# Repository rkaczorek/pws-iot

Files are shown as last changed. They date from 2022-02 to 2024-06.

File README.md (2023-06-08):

# pws-iot
Personal Weather Station IoT. It reads various environmental sensors and publishes values to MQTT server via wireless connection.

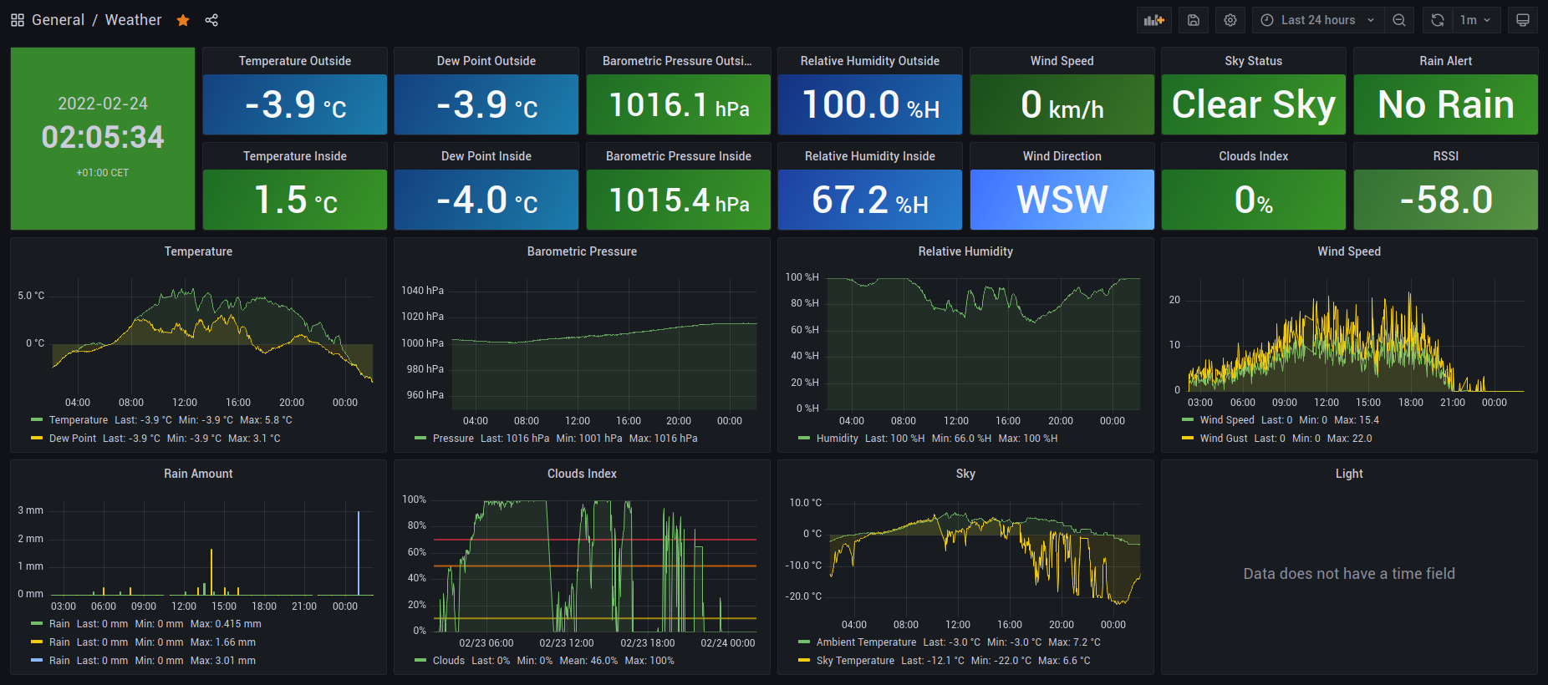
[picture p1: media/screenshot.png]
alt img1


# Features
- Weather Sensors
    - Temperature
    - Humidity
    - Pressure
    - Dew Point
    - Wind Speed
    - Wind Gust
    - Wind Direction
    - Rain Gauge
    - Clouds
    - Light
- WiFi connection
- MQTT messaging
- Manual or Auto polling
- Home Assistant integration

# Requirements
- MQTT server
- Node-Red (optional - only for routing data to InfluxDB)
- InfluxDB (optional - only for data persistency)

# Supported MCUs
- Arduino Nano 33 IoT
- Arduino MKR WiFi 1000
- Arduino MKR WiFi 1010
- Arduino Uno Wifi Rev2
- ESP8266

# Supported GPIO connected (A0, D10, D11) sensors
- Weather Meters (wind direction, wind speed, rainfall) (https://www.sparkfun.com/products/8942)

# Supported I2C sensors
- BME280 (temperature, humidity, pressure)
- MLX90614 (ambient temperature, object temperature)
- VEML7700 (light)

# Home Assistant
You can easily integrate Personal Weather Station IoT with your Home Assistant.
Just make sure that MQTT Integration is installed on Home Assistant. We are using Home Assistant 
autodiscovery feature to add Personal Weather Station device and sensor entities automatically.

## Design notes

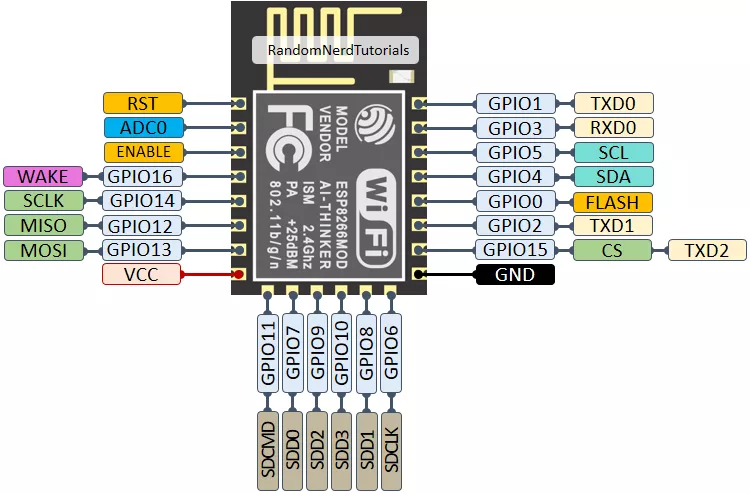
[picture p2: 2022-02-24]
hardware/Pinouts/Pinout-ESP8266-ESP-12E.png

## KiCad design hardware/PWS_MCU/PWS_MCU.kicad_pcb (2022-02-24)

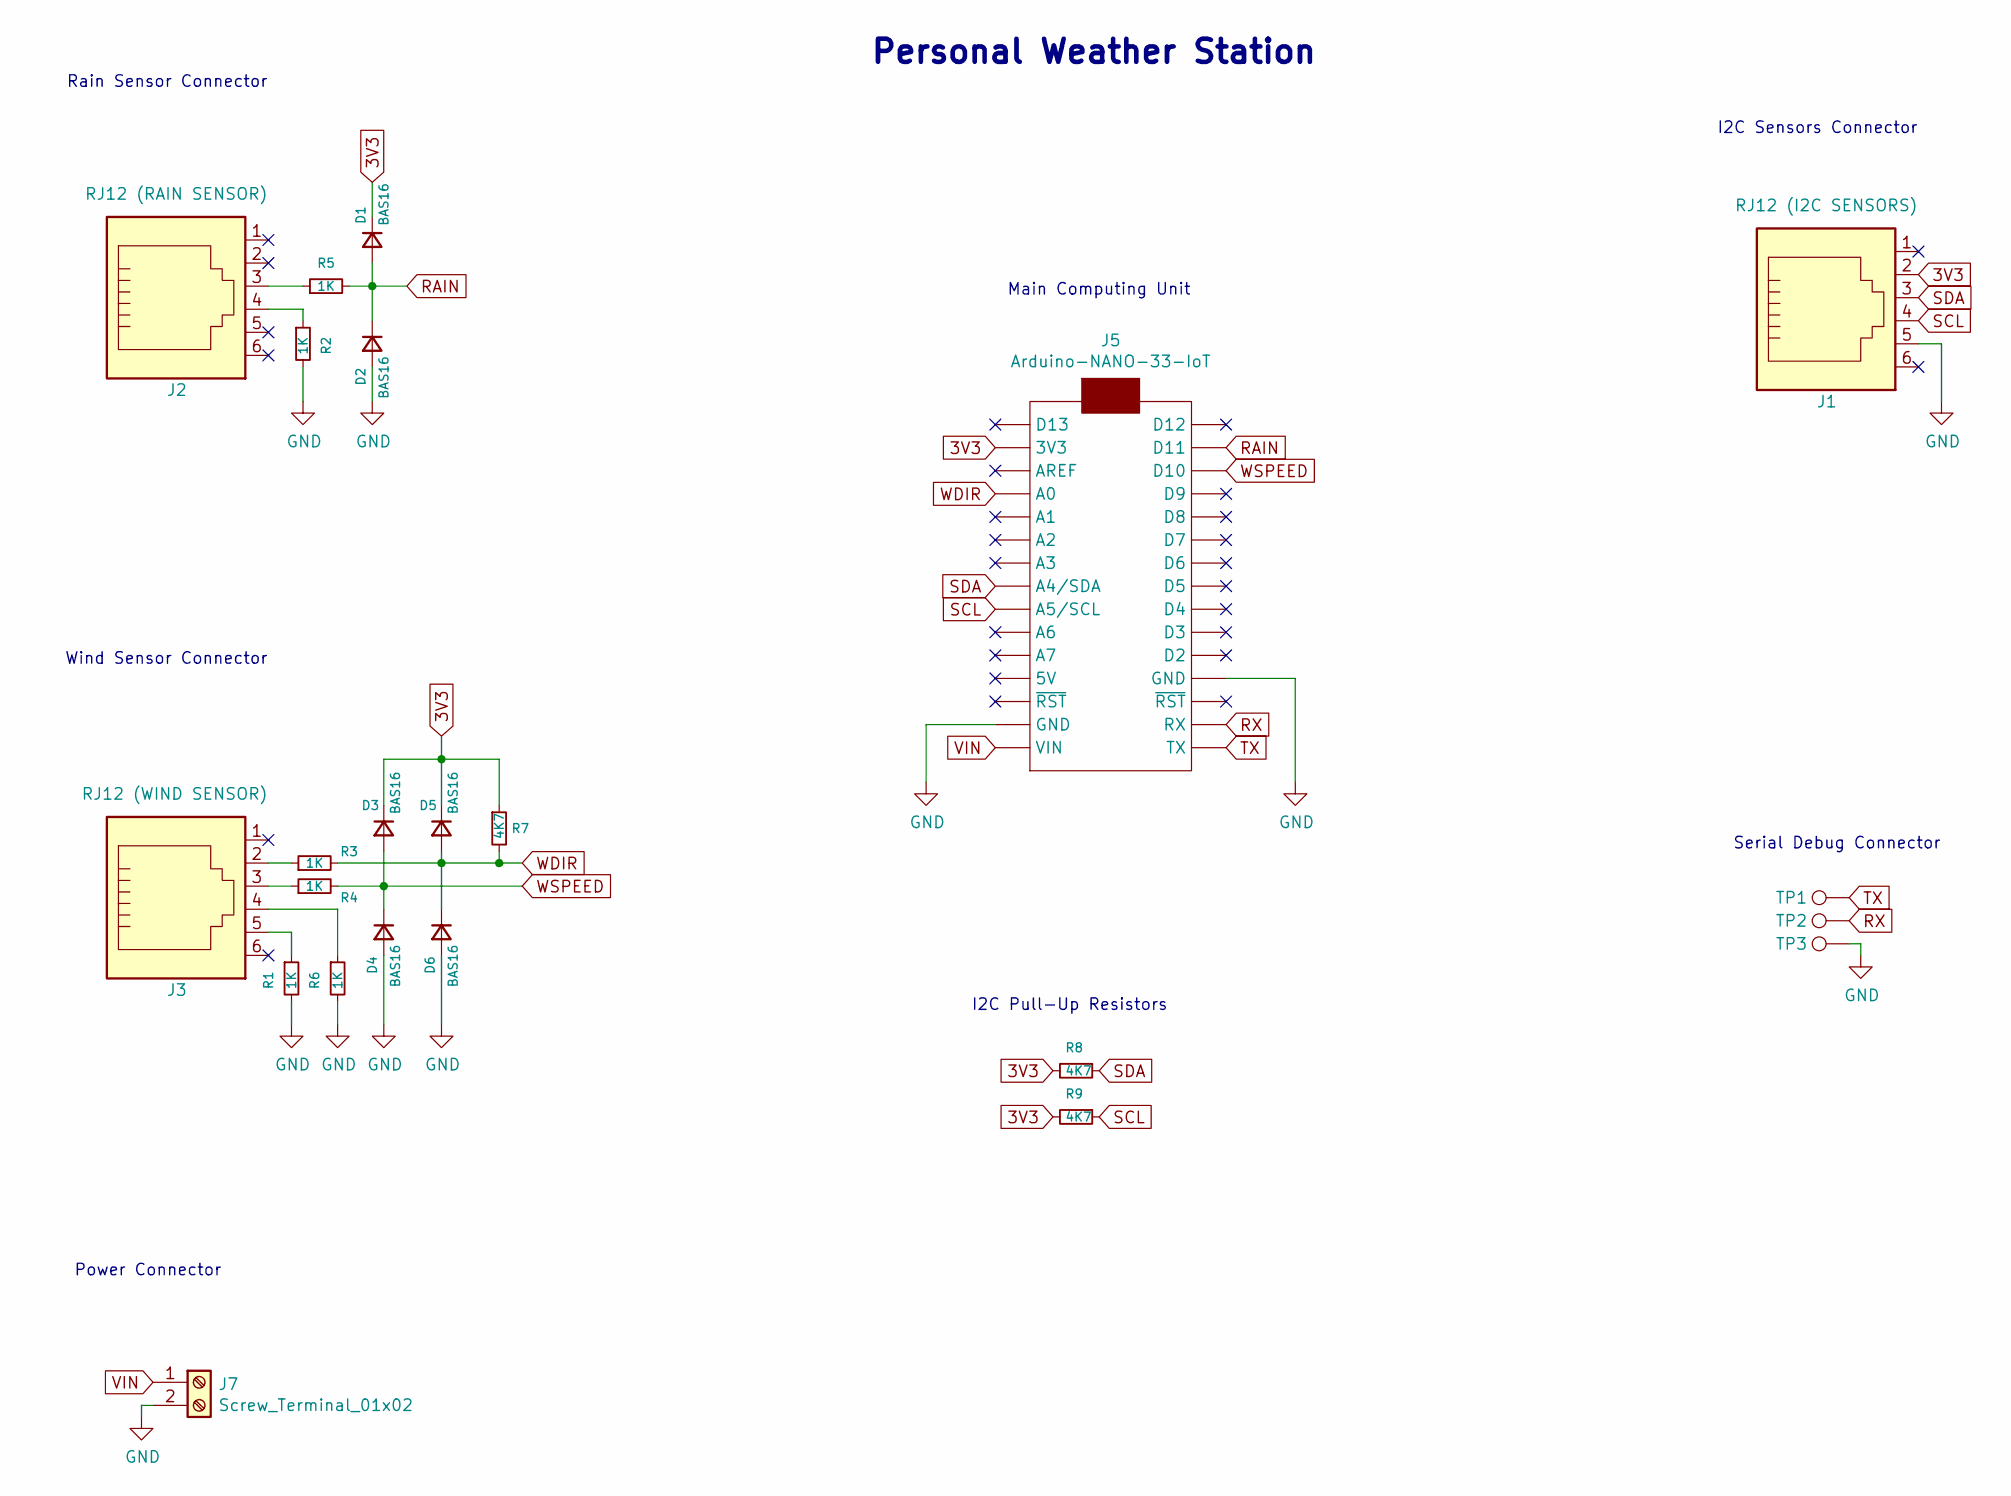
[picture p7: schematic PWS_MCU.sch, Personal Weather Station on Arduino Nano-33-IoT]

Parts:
D1, D2, D3, D4, D5, D6: BAS16; D_SOD-123
J1: RJ12 (I2C SENSORS); molex_6p6c
J2: RJ12 (RAIN SENSOR); molex_6p6c
J3: RJ12 (WIND SENSOR); molex_6p6c
J5: Arduino-NANO-33-IoT; NANO_33_Footprint_SMD_Castell
J7: Screw_Terminal_01x02; TerminalBlock_Phoenix_MPT-2.54mm_2pol
R1, R2, R3, R4, R5, R6: 1K; R_0603_HandSoldering
R7, R8, R9: 4K7; R_0603_HandSoldering
TP1, TP2, TP3: TestPoint; Measurement_Point_Square-SMD-Pad_Small

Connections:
3V3: D1.1 (K), D3.1 (K), D5.1 (K), J1.2, J5.2 (3V3), R7.1, R8.2, R9.2
GND: D2.2 (A), D4.2 (A), D6.2 (A), J1.5, J5.14 (GND), J5.19 (GND), J7.2, R1.2, R2.2, R6.2, TP3.1
unnamed: J2.3, R5.1
unnamed: J2.4, R2.1
unnamed: J3.2, R3.1
unnamed: J3.3, R4.1
unnamed: J3.4, R6.1
unnamed: J3.5, R1.1
RAIN: D1.2 (A), D2.1 (K), J5.29 (D11), R5.2
RX: J5.17 (RX), TP2.1
SCL: J1.4, J5.9 (A5/SCL), R9.1
SDA: J1.3, J5.8 (A4/SDA), R8.1
TX: J5.16 (TX), TP1.1
VIN: J5.15 (VIN), J7.1
WDIR: D5.2 (A), D6.1 (K), J5.4 (A0), R3.2, R7.2
WSPEED: D3.2 (A), D4.1 (K), J5.28 (D10), R4.2

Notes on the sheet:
Main Computing Unit
Rain Sensor Connector
Wind Sensor Connector
I2C Pull-Up Resistors
I2C Sensors Connector
Serial Debug Connector
Personal Weather Station
Power Connector

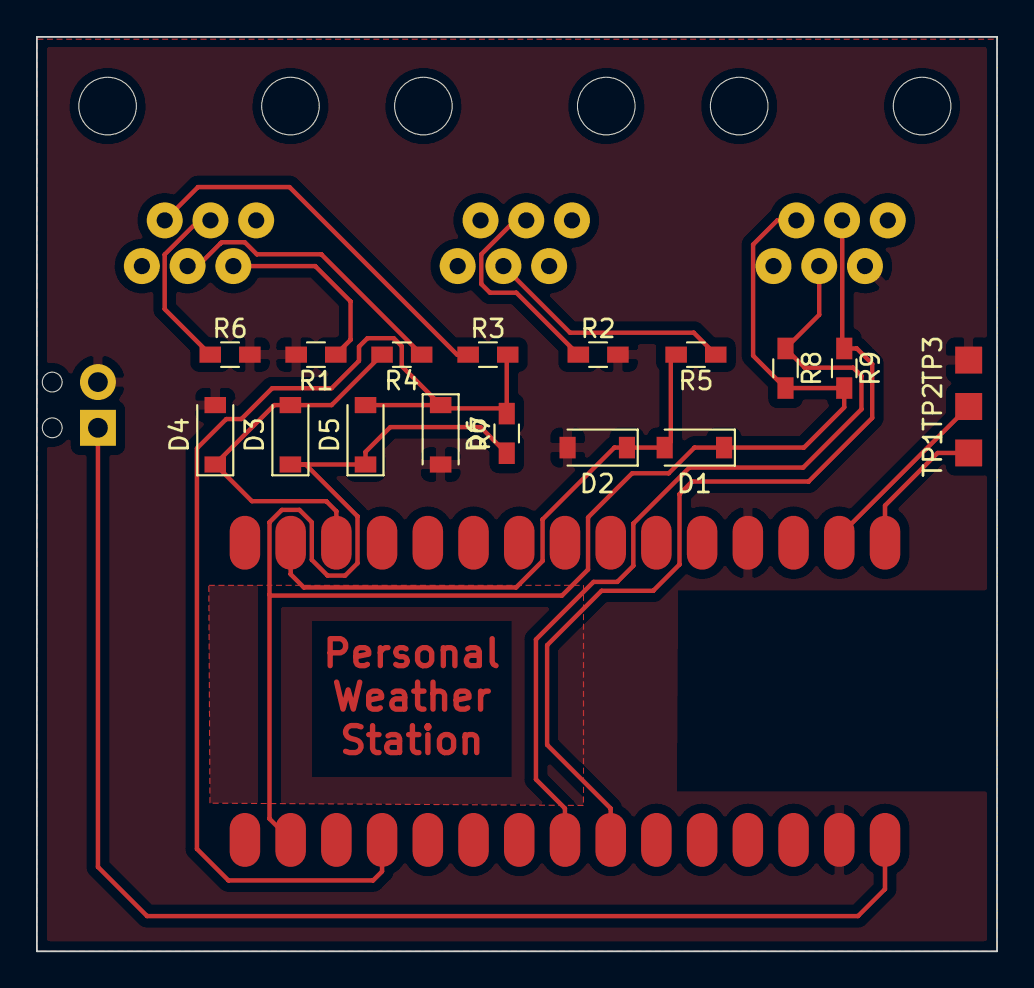
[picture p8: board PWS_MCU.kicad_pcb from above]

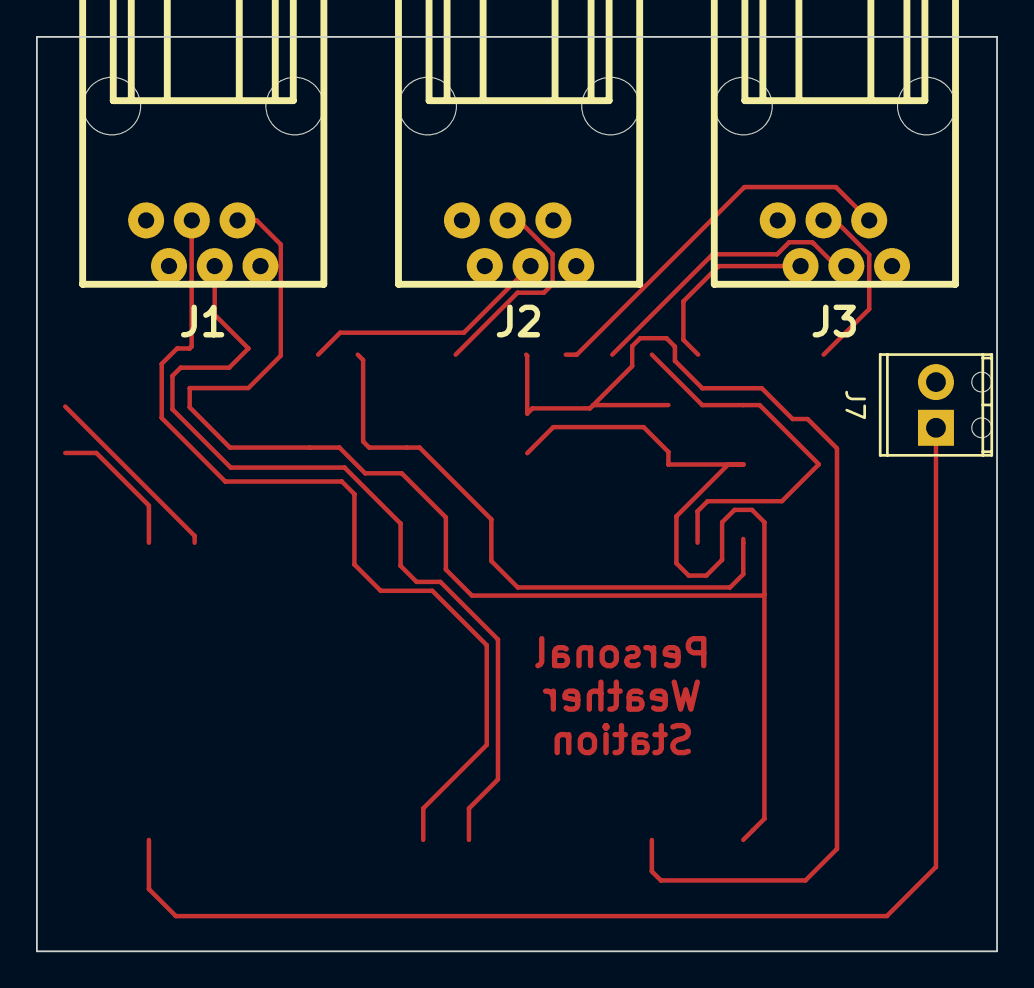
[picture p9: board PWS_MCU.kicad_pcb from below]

Board: 2 copper layers, 53.3 x 50.8 mm, 23 parts (4 on the bottom side), 16 nets.

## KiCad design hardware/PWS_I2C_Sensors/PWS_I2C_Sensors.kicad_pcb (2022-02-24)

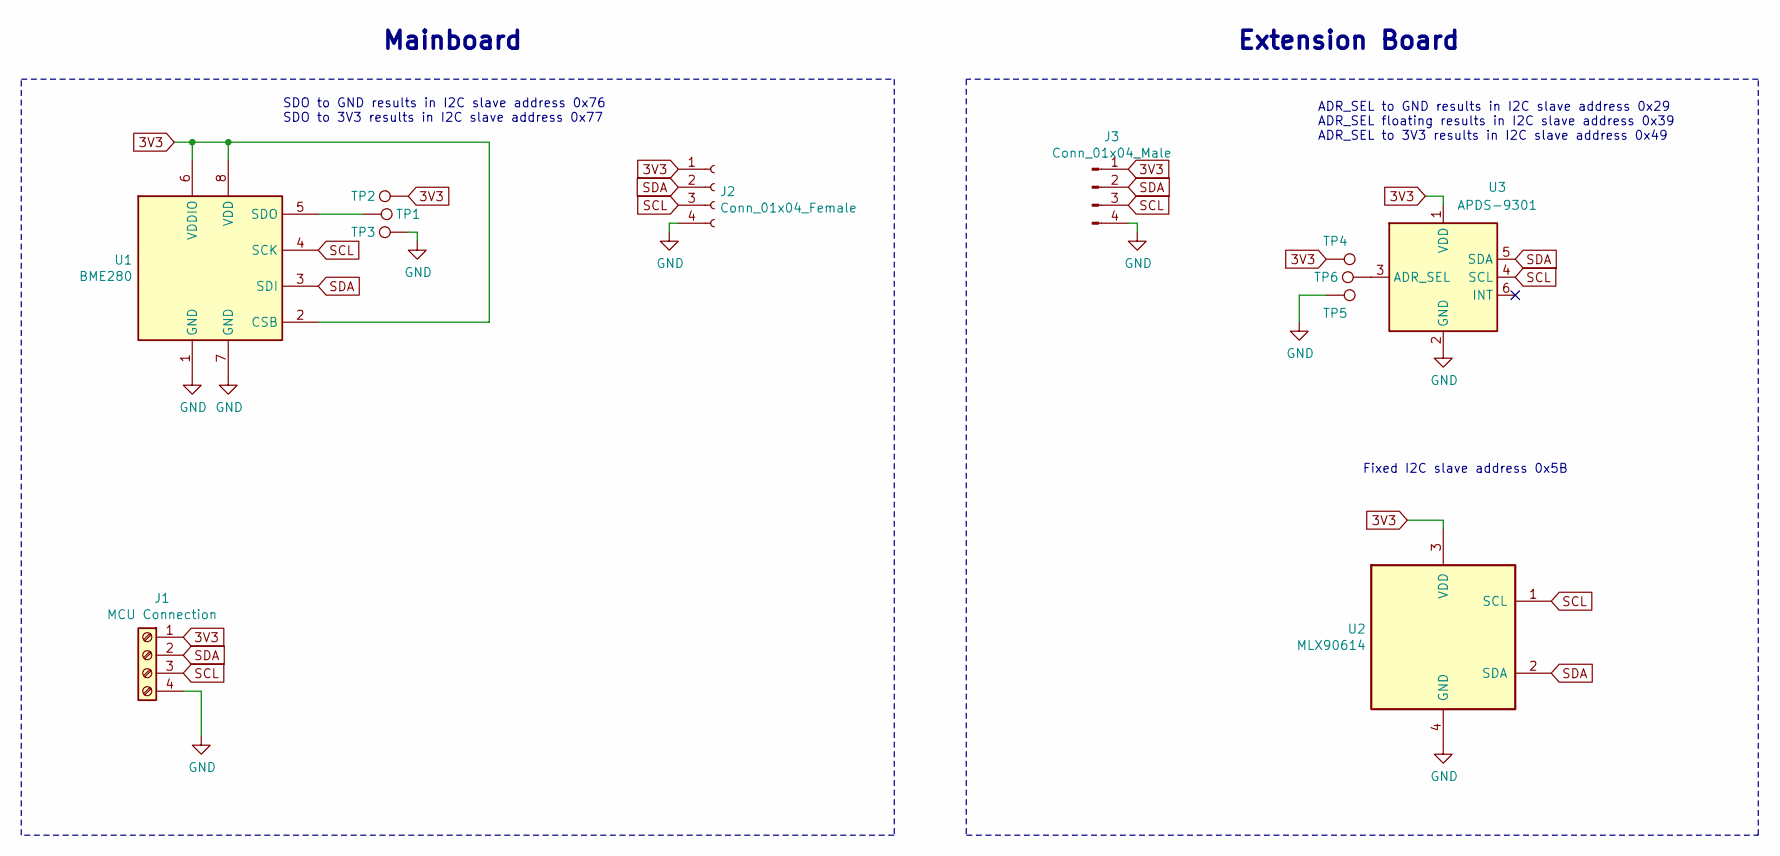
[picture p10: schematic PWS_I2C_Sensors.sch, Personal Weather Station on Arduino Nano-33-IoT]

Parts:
J1: MCU Connection; TerminalBlock_Phoenix_MPT-2.54mm_4pol
J2: Conn_01x04_Female; Pin_Header_Angled_1x04_Pitch2.54mm
J3: Conn_01x04_Male; Pin_Header_Straight_1x04_Pitch2.54mm
TP1, TP2, TP3, TP4, TP5, TP6: TestPoint; Measurement_Point_Square-SMD-Pad_Small
U1: BME280; Bosch_LGA-8_2.5x2.5mm_Pitch0.65mm_ClockwisePinNumbering
U2: MLX90614
U3: APDS-9301; Broadcom_APDS-9301

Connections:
3V3: J1.1, J2.1, J3.1, TP2.1, TP4.1, U1.2 (CSB), U1.6 (VDDIO), U1.8 (VDD), U2.3 (VDD), U3.1 (VDD)
GND: J1.4, J2.4, J3.4, TP3.1, TP5.1, U1.1 (GND), U1.7 (GND), U2.4 (GND), U3.2 (GND)
unnamed: TP1.1, U1.5 (SDO)
unnamed: TP6.1, U3.3 (ADR_SEL)
SCL: J1.3, J2.3, J3.3, U1.4 (SCK), U2.1 (SCL), U3.4 (SCL)
SDA: J1.2, J2.2, J3.2, U1.3 (SDI), U2.2 (SDA), U3.5 (SDA)

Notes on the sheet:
Mainboard
Extension Board
SDO to GND results in I2C slave address 0x76 SDO to 3V3 results in I2C slave address 0x77
ADR_SEL to GND results in I2C slave address 0x29 ADR_SEL floating results in I2C slave address 0x39 ADR_SEL to 3V3 results in I2C slave address 0x49
Fixed I2C slave address 0x5B

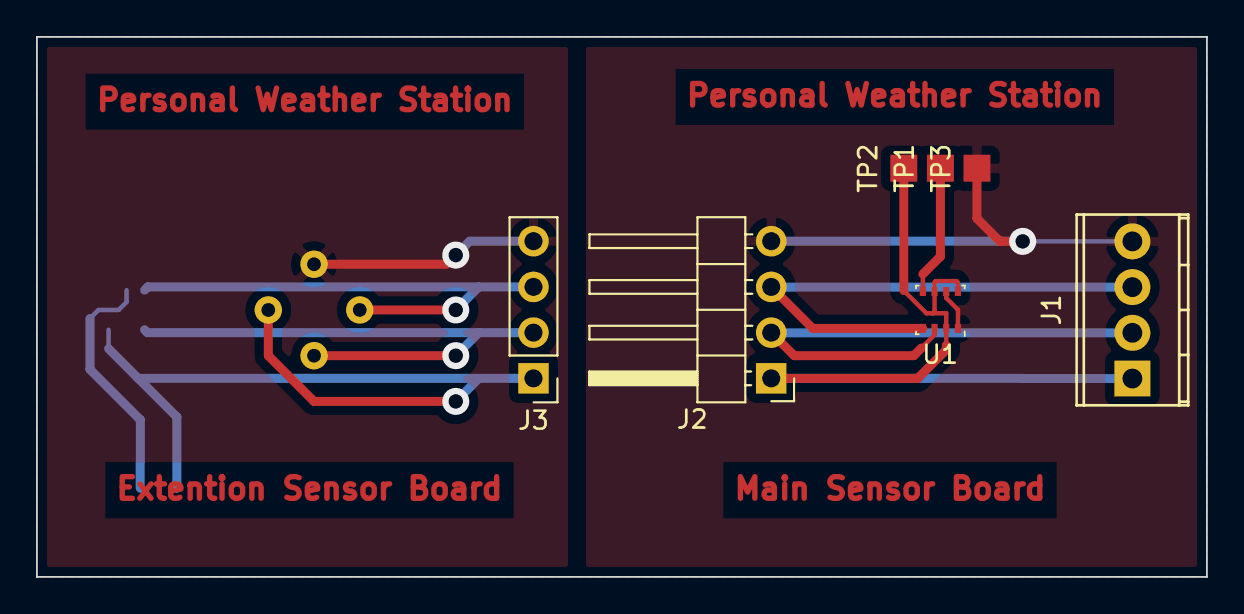
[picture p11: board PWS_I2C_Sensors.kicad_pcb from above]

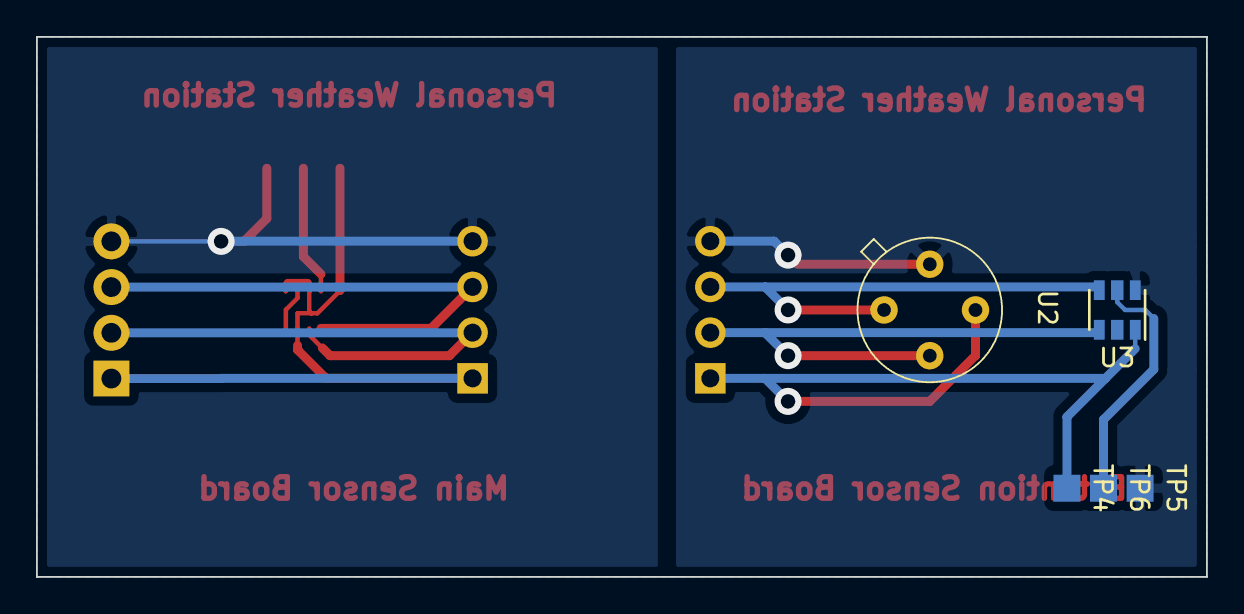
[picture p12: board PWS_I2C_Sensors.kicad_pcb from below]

Board: 2 copper layers, 65.0 x 30.0 mm, 12 parts (5 on the bottom side), 6 nets.

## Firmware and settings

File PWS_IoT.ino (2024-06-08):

/*
  Name: Personal Weather Station IoT
  By: Radek Kaczorek, (C) 2021 - 2024
  License: GNU General Public License v3.0

  This code reads various environmental sensors and publishes values to MQTT server via wireless connection.

  Supported MCUs:
  - Arduino Nano 33 IoT
  - Arduino MKR WiFi 1000
  - Arduino MKR WiFi 1010
  - Arduino Uno Wifi Rev2
  - ESP8266

  Supported GPIO connected (A0, D10, D11) sensors:
  - Weather Meters (wind direction, wind speed, rainfall) (https://www.sparkfun.com/products/8942)

  Supported I2C sensors:
  - BME280 (temperature, humidity, pressure)
  - MLX90614 (ambient temperature, object temperature)
  - VEML7700 (light)

  Set these variables in PWS_IoT.h:
    WIFI_SSID "wifi_name"
    WIFI_PASS "wifi_password"
    MQTT_HOST "mqtt_address"
    MQTT_PORT 1883
    MQTT_USER "mqtt_user"
    MQTT_PASS "mqtt_password"
    MQTT_ROOT_TOPIC "environment"
    MQTT_DEVICE_ID "pws"
    MQTT_DEVICE_ID_TO_HOSTNAME true
    DEBUG false
    WIND_DIR_CORRECTION 60
    WIND_AVERAGING_TIME 10000
    CLOUDS_AVERAGING_TIME 5000
    HOMEASSISTANT
    HA_DISCOVERY_TOPIC
*/

#define VERSION 1.4

#include "PWS_IoT.h"

#if defined(ARDUINO_SAMD_MKRWIFI1010) || defined(ARDUINO_SAMD_NANO_33_IOT) || defined(ARDUINO_AVR_UNO_WIFI_REV2)
  #include <WiFiNINA.h> // https://www.arduino.cc/en/Reference/WiFiNINA // https://github.com/arduino-libraries/WiFiNINA
#elif defined(ARDUINO_SAMD_MKR1000)
  #include <WiFi101.h> // https://www.arduino.cc/en/Reference/WiFi101
#elif defined(ARDUINO_ESP8266_ESP12)
  #include <ESP8266WiFi.h> // https://github.com/esp8266/Arduino/tree/master/libraries/ESP8266WiFi
#endif

#include <Wire.h> // https://github.com/esp8266/Arduino/tree/master/libraries/Wire
#include <ArduinoMqttClient.h> // https://github.com/arduino-libraries/ArduinoMqttClient
#include <ArduinoOTA.h> // https://github.com/jandrassy/ArduinoOTA
#include <ArduinoJson.h>  // https://github.com/bblanchon/ArduinoJson
#include <Adafruit_BME280.h> // https://github.com/adafruit/Adafruit_BME280_Library
#include <Adafruit_MLX90614.h> // https://github.com/adafruit/Adafruit-MLX90614-Library
#include <Adafruit_VEML7700.h> // https://github.com/adafruit/Adafruit_VEML7700
#include <Cardinal.h> // https://github.com/DaAwesomeP/arduino-cardinal
#include <SimpleTime.h>

#include <vector>
#include <numeric>

#define SEALEVELPRESSURE_HPA  (1013.25) // used for altitude calculation based on pressure
#define sgn(x) ((x) < 0 ? -1 : ((x) > 0 ? 1 : 0)) // used for arithmetic sign of a value (needed by cloud detection algorithm)

// Debug
bool DEBUG = false;

// ===================================================================
//                       Enable/Disable sensors
// ===================================================================
// -------------------------- autodetected ---------------------------
int bme_sensor = 0; // Temperature, Humidity, Pressure
int mlx_sensor = 0; // Sky temperature / Clouds
int wind_sensor = 0; // Wind Speed - set to 1 to enable
int veml_sensor = 0; // Light
// -------------------------- set manually ---------------------------
int rainfall_sensor = 1; // Rainfall - set to 1 to enable
// ===================================================================

// hardware pins definitions
const byte WDIR = A0;
const byte WSPEED = 10;
const byte RAINFALL = 11;

// volatiles are subject to modification by IRQs
volatile long lastWindIRQ = 0;
volatile long windClicks = 0;
volatile long lastRainIRQ = 0;
volatile long rainClicks = 0;

// last checks
unsigned long lastWindMillis = 0;
unsigned long lastCloudsMillis = 0;
unsigned long lastCheck = 0;

// statistical vars
std::vector<float> windSpeed;
std::vector<int> windDir;
float windGustSpeed = 0;
std::vector<int> windGustDir;
std::vector<float> irAmbient;
std::vector<float> irSky;

// polling vars
unsigned long timestamp = 0; // set tickmark for auto polling
unsigned int polling = 60; // auto polling time

// mqtt
const char* mqtt_host = MQTT_HOST;
int mqtt_port = MQTT_PORT;
const char* mqtt_user = MQTT_USER;
const char* mqtt_pass = MQTT_PASS;

// mqtt topics
char mqtt_root_topic[32] = MQTT_ROOT_TOPIC; // eg. environment
char mqtt_device_id[32] = MQTT_DEVICE_ID; // eg. mysensor
char mqtt_device_topic[64]; // = mqtt_root_topic/mqtt_device_id
char mqtt_setroot_topic[36]; // eg. environment/set
char mqtt_setname_topic[70]; // eg. environment/mysensor/set
char mqtt_status_topic[76]; // eg. environment/mysensor/status
char mqtt_poll_topic[71]; // eg. environment/mysensor/poll
char mqtt_control_topic[74]; // eg. environment/mysensor/control

byte mac[6]; // 6 byte array to hold the MAC address
char hostname[32]; // an array to hold wifi hostname

WiFiClient wifiClient;
MqttClient mqttClient(wifiClient);
int wifiStatus = WL_IDLE_STATUS;
WiFiServer server(23);

Adafruit_BME280 bme; // BME280 sensor - temperature, humidity, pressure
Adafruit_MLX90614 mlx = Adafruit_MLX90614(); // MLX90614 sensor - infrared termometer
Adafruit_VEML7700 veml = Adafruit_VEML7700(); // VEML7700 sensor - ambient light

Cardinal cardinal; // Cardinal direction NESW

void rainfallIRQ()
{
  if (millis() - lastRainIRQ > 10) // ignore switch-bounce glitches less than 10ms
  {
    lastRainIRQ = millis();
    rainClicks++;
  }
}

void windspeedIRQ()
{
  if (millis() - lastWindIRQ > 10) // Ignore switch-bounce glitches less than 10ms
  {
    lastWindIRQ = millis();
    windClicks++;
  }
}

void setup() {
  pinMode(LED_BUILTIN, OUTPUT); // led
  pinMode(WDIR, INPUT); // input from winddir sensor
  pinMode(WSPEED, INPUT_PULLUP); // input from windspeed sensor
  pinMode(RAINFALL, INPUT_PULLUP); // input from rain gauge sensor

  // attach external interrupt pins to IRQ functions
  attachInterrupt(digitalPinToInterrupt(RAINFALL), rainfallIRQ, FALLING);
  attachInterrupt(digitalPinToInterrupt(WSPEED), windspeedIRQ, FALLING);

  // turn on interrupts
  interrupts();

  Serial.begin(9600);
  delay(3000); // wait for serial port to connect. Needed for native USB port only

  blinkLED(1);

Serial.println("====================================");
  Serial.print("|  Personal Weather Station v");
  Serial.print(VERSION);
  Serial.println("  |");
  Serial.println("====================================");
  Serial.println("");

  // List all available I2C devices
  if (DEBUG)
    getI2Cdevices();

  // Init sensors
  Serial.println("Initializing sensors...");

  // Init BME280
  if (bme.begin(0x76) || bme.begin(0x77)) { // i2c slave address: 0x76 or 0x77
    Serial.println("  - BME280 sensor\tOK");
    bme_sensor = 1;
    bme.setSampling(Adafruit_BME280::MODE_FORCED,
                    Adafruit_BME280::SAMPLING_X1, // temperature
                    Adafruit_BME280::SAMPLING_X1, // pressure
                    Adafruit_BME280::SAMPLING_X1, // humidity
                    Adafruit_BME280::FILTER_OFF
                  );
  } else {
    Serial.println("  - BME280 sensor\tERROR");
    bme_sensor = 0;
  }

  // Init MLX
  if (mlx.begin()) { // i2c slave address: 0x5a
    Serial.println("  - MLX90614 sensor\tOK");
    mlx_sensor = 1;
  } else {
    Serial.println("  - MLX90614 sensor\tERROR");
    mlx_sensor = 0;
  }

  // Init VEML
  if (veml.begin()) { // i2c slave address: 0x10
    veml_sensor = 1;
    Serial.println("  - VEML sensor\t\tOK");
  } else {
    veml_sensor = 0;
    Serial.println("  - VEML sensor\t\tERROR");
  }

  // Rainfall sensor
  if (rainfall_sensor) {
    Serial.println("  - Rainfall sensor\tOK");
  } else {
    Serial.println("  - Rainfall sensor\tERROR");
  }

  // Wind sensors
  int winddir = get_wind_direction();
  if (winddir != -1)
  {
    wind_sensor = 1;
  } else {
    wind_sensor = 0;
  }

  if (wind_sensor) {
    Serial.println("  - Wind sensors\tOK");
  } else {
    Serial.println("  - Wind sensors\tERROR");
  }

  // Enable autodiscovery of sensors for Home Assistant
  if (HOMEASSISTANT) {
    Serial.println("Home Assistant MQTT integration ENABLED");

    if (DEBUG) {
      Serial.print("Autodiscovery topic: ");
      Serial.println(HA_DISCOVERY_TOPIC);
    }
  
    // Default - always available
    initHAEntity("status", "sensor", NULL, NULL, "mdi:connection", "Status");
    initHAEntity("last_seen", "sensor", "timestamp", NULL, "mdi:clock", "Last Seen");
    initHAEntity("poll", "sensor", NULL, "s", "mdi:clock", "Update Interval");
    initHAEntity("rssi", "sensor", "signal_strength", "dBm", NULL, "RSSI");

    // Rainfall
    if (rainfall_sensor) {
      initHAEntity("rainfall", "sensor", "precipitation", "mm", NULL, "Rainfall");
    }

    // Wind Speed & Direction
    if (wind_sensor) {
      initHAEntity("wind_speed", "sensor", "wind_speed", "km/h", NULL, "Wind Speed");
      initHAEntity("wind_gust_speed", "sensor", "wind_speed", "km/h", NULL, "Wind Gust Speed");
      initHAEntity("wind_dir", "sensor", NULL, "°", "mdi:compass", "Wind Direction");
      initHAEntity("wind_dir_cardinal", "sensor", NULL, NULL, "mdi:compass", "Wind Direction");
      initHAEntity("wind_gust_dir", "sensor", NULL, "°", "mdi:compass", "Wind Gust Direction");
      initHAEntity("wind_gust_dir_cardinal", "sensor", NULL, NULL, "mdi:compass", "Wind Gust Direction");
    }

    // BME
    if (bme_sensor) {
      initHAEntity("temperature", "sensor", "temperature", "°C", NULL, "Temperature");
      initHAEntity("humidity", "sensor", "humidity", "%", NULL, "Humidity");
      initHAEntity("dew_point", "sensor", "temperature", "°C", NULL, "Dew Point");
      initHAEntity("pressure", "sensor", "atmospheric_pressure", "hPa", NULL, "Pressure");
    }    

    // MLX
    if (mlx_sensor) {
      initHAEntity("ir_ambient", "sensor", "temperature", "°C", NULL, "IR Ambient Temperature");
      initHAEntity("ir_sky", "sensor", "temperature", "°C", NULL, "IR Sky Temperature");
      initHAEntity("clouds", "sensor", NULL, "%", "mdi:cloud", "Clouds");
    }

    // VEML
    if (veml_sensor) {
      initHAEntity("light", "sensor", "illuminance", "lx", NULL, "Light");
    }

  } else {
      Serial.println("Home Assistant integration DISABLED");
  }

  Serial.println("");

  // Ready
  Serial.println("Personal Weather Station OK");
  blinkLED(4);
}

void loop() {
  wifiConnect(); // Autoconnect WiFi
  mqttConnect(); // Autoconnect MQTT
  telnetCommand();

  // collect wind sensors data every loop
  if (millis() - lastWindMillis > WIND_AVERAGING_TIME) {

    if (DEBUG)
      telnetDebug("Wind sensors:");

    // get wind direction
    int winddir = get_wind_direction();

    if (DEBUG)
      telnetDebug(winddir);
    
    if (winddir != -1) {
      wind_sensor = 1; // we have readings - ENABLE
      // calculate corrected wind direction
      winddir += WIND_DIR_CORRECTION;
      if(winddir >= 360) winddir -= 360;
      if(winddir < 0) winddir += 360;
      windDir.push_back(winddir);
    } else {
      wind_sensor = 0; // we do not have readings - DISABLE
    }

    if (wind_sensor) {
      // get wind speed
      float windspeed = (float) windClicks / (WIND_AVERAGING_TIME / 1000); // clicks per second

    if (DEBUG)
      telnetDebug(windspeed);

      windClicks = 0;
      windspeed *= 2.4011412; // 1 click per second equals 1.492MPH = 2.4011412 km/h
      windSpeed.push_back(windspeed);      

      // get wind gust and wind gust direction
      if (windspeed > windGustSpeed) {
        windGustSpeed = windspeed;
        if (winddir != -1) {
          windGustDir.push_back(winddir);
        }
      }
    }

    lastWindMillis = millis();
  }

  // collect clouds sensors data every loop
  if (millis() - lastCloudsMillis > CLOUDS_AVERAGING_TIME) {

    if (DEBUG)
      telnetDebug("Sky sensors:");

    // get ambient temperature and sky temperature
    if (mlx_sensor) {
      float temperature_ambient = ((int) (mlx.readAmbientTempC() * 100)) / 100.0; // celcius
      float temperature_sky = ((int) (mlx.readObjectTempC() * 100)) / 100.0; // celcius

      if (DEBUG) {
        telnetDebug(temperature_ambient);
        telnetDebug(temperature_sky);
      }

      if (temperature_ambient > -273.0 && temperature_sky > -273.0) { // sanity check
        irAmbient.push_back(temperature_ambient);
        irSky.push_back(temperature_sky);
      }
    }
    lastCloudsMillis = millis();
  }
  autoPolling();
}

void telnetDebug(const char* payload) {
  for (unsigned int i = 0; i < strlen(payload); i++)
    server.write(payload[i]);
  server.write("\n");
}

void telnetDebug(float val) {
    char payload[16];
    sprintf(payload, "%f", val);
    telnetDebug(payload);
}

void telnetCommand() {
  if (WiFi.status() != WL_CONNECTED)
    return;

  WiFiClient client = server.available();

  if (client) {
    if (!client.connected()) {
      client.flush(); // clear out the input buffer
    }

    if (client.available() > 0) {
      char command = client.read();
      if (command == 'h') {
        telnetDebug("========================");
        telnetDebug("Personal Weather Station");
        telnetDebug("========================");
        telnetDebug("press h to display help");
        telnetDebug("press q to restart device");
        telnetDebug("press d to toggle debug");
      }
      if (command == 'q') {
        mqttPublishStatus(0);
        restartDevice();
      }
      if (command == 'd') {
        DEBUG = !DEBUG;
      }
    }
  }
}

void restartDevice() {
  telnetDebug("Restarting device in 3 seconds...");
  Serial.println("Restarting device in 3 seconds...");
  delay(3000);
  NVIC_SystemReset();
}

void autoPolling() {
  if ( polling == 0 || millis() - timestamp < polling * 1000)
    return;
  getSensors();
  timestamp = millis();
}

void wifiConnect() {
  int count = 0;

  if (WiFi.status() == WL_CONNECTED) {
    ArduinoOTA.poll(); // check for WiFi OTA updates
    return;
  }

  // Check for the WiFi module:
  if (WiFi.status() == WL_NO_MODULE) {
    Serial.println("Communication with WiFi module failed!");
    restartDevice();
  }
  
  WiFi.macAddress(mac);
  sprintf(hostname, "pws-%x%x", mac[1], mac[0]);
  WiFi.setHostname(hostname);

  Serial.print("Connecting to WiFi... ");
  do
  {
    wifiStatus = WiFi.begin(WIFI_SSID, WIFI_PASS);
    delay(100);
  }
  while (wifiStatus != WL_CONNECTED && count++ < 5 );

  if (WiFi.status() == WL_CONNECTED) {
    Serial.println("OK");
    if (DEBUG) {
      Serial.print("  - SSID: ");
      Serial.println(WIFI_SSID);
      Serial.print("  - Hostname: ");
      Serial.println(hostname);
      Serial.print("  - IP address: ");
      Serial.println(WiFi.localIP());
      Serial.print("  - Subnet mask: ");
      Serial.println(WiFi.subnetMask());
      Serial.print("  - Default gateway: ");
      Serial.println(WiFi.gatewayIP());
      Serial.println();
    }
    ArduinoOTA.begin(WiFi.localIP(), OTA_USER, OTA_PASS, InternalStorage); // Start the WiFi OTA
    server.begin(); // Start telnet server
  } else {
    Serial.println("ERROR");
    restartDevice();
  }
}

void mqttConnect() {
  mqttClient.poll(); // send MQTT keep alives

  if (mqttClient.connected()) {
    return;
  }

  Serial.print("Connecting to the MQTT broker... ");

  // set MQTT device name to hostname
  if (MQTT_DEVICE_ID_TO_HOSTNAME) {
    strcpy(mqtt_device_id, hostname);
  }

  // convert MQTT device name to lower case
  for (unsigned int i = 0; i < strlen(mqtt_device_id); i++)
    mqtt_device_id[i] = tolower(mqtt_device_id[i]);

  // construct MQTT topics
  sprintf(mqtt_device_topic, "%s/%s", mqtt_root_topic, mqtt_device_id); // simplified device topic
  sprintf(mqtt_status_topic, "%s/status", mqtt_device_topic); // device status

  // device control via MQTT
  sprintf(mqtt_setroot_topic, "%s/set", mqtt_root_topic); // setting root name
  sprintf(mqtt_setname_topic, "%s/set", mqtt_device_topic);   // setting device name
  sprintf(mqtt_control_topic, "%s/control", mqtt_device_topic); // controling device
  sprintf(mqtt_poll_topic, "%s/poll", mqtt_device_topic); // setting polling time (configurable via mqtt)

  mqttClient.setId(mqtt_device_id);
  mqttClient.setUsernamePassword(mqtt_user, mqtt_pass);
  //mqttClient.setCleanSession(true); // http://docs.oasis-open.org/mqtt/mqtt/v3.1.1/os/mqtt-v3.1.1-os.html#_Keep_Alive
  //mqttClient.setKeepAliveInterval(60*1000L);
  //mqttClient.setConnectionTimeout(60*1000L);

  // set callback
  mqttClient.onMessage(mqttCallback);
  
  if (mqttClient.connect(mqtt_host, mqtt_port)) {
    Serial.println("OK");
    if (DEBUG) {
      Serial.print("  - Host: ");
      Serial.print(mqtt_host);
      Serial.print(":");
      Serial.println(mqtt_port);
      Serial.print("  - Client ID: ");
      Serial.println(mqtt_device_id);
      Serial.print("  - Topic: ");
      Serial.print(mqtt_root_topic);
      Serial.print("/");
      Serial.println(mqtt_device_id);
      Serial.println();
    }

    // set last will message
    String lastWill = "offline";
    mqttClient.beginWill(mqtt_status_topic, lastWill.length(), true, 1);
    mqttClient.print(lastWill);
    mqttClient.endWill();
  
    // Subscribe to control topics
    mqttSubscribe();

    // Publish status
    mqttPublishStatus(1);
  } else {
    Serial.print("ERROR");
    if (DEBUG) {
      Serial.print(" (");
      switch (mqttClient.connectError()) {
        case -2:
          Serial.print("Connection refused");
          break;
        case -1:
          Serial.print("Connection timeout");
          break;
        case 1:
          Serial.print("Unacceptable protocol version");
          break;
        case 2:
          Serial.print("Identifier rejected");
          break;
        case 3:
          Serial.print("Server unavailable");
          break;
        case 4:
          Serial.print("Bad username or password");
          break;
        case 5:
          Serial.print("Not authorized");
          break;
        default:
          Serial.print("Connection refused");
      }
      Serial.println(")");
    } else {
      Serial.println();
    }
  }
}

bool mqttSubscribe() {
  Serial.print("Subscribing to control topics... ");
  if (mqttClient.subscribe(mqtt_poll_topic) && mqttClient.subscribe(mqtt_control_topic)) {
    // successfully subscribed to topics
    Serial.println("OK");
    if(DEBUG) {
      Serial.print("  - Publish '0' to ");
      Serial.print(mqtt_poll_topic);
      Serial.println(" to request sensors reading or publish an integer number to set auto polling in seconds");
      Serial.print("  - Publish command to "); // note: 'restart' command available only
      Serial.print(mqtt_control_topic);
      Serial.println(" to control the device");
      Serial.println("");
    }
    return true;
  } else {
    Serial.println("ERROR");
    Serial.println("");
    return false;
  }
}

void mqttPublishStatus(int status)
{
  String payload = "online";
  bool retain = false;
  int qos = 0;

  if ( status == 0 ) {
    payload = "offline";
    retain = false;
    qos = 0;
  }

  mqttClient.beginMessage(mqtt_status_topic, payload.length(), retain, qos, false);
  mqttClient.print(payload);
  mqttClient.endMessage();
}

void mqttPublishWeather(const char* topic, float val) {
  char mqtt_topic[512] = "";
  char msg[16];
  sprintf(mqtt_topic, "%s/%s", mqtt_device_topic, topic);
  sprintf(msg, "%0.2f", val);

  bool retain = false;
  int qos = 0;

  mqttClient.beginMessage(mqtt_topic, retain, qos);
  mqttClient.print(msg);
  mqttClient.endMessage();

  if (DEBUG) {
    Serial.println("");
    Serial.println("MQTT message published");
    Serial.print("  topic: ");
    Serial.print(mqtt_topic);
    Serial.println("");
    Serial.print("  message: ");
    Serial.println(msg);
    Serial.println("");
  }
}

void mqttPublishWeather(const char* topic, const char* msg) {
  char mqtt_topic[512] = "";
  sprintf(mqtt_topic, "%s/%s", mqtt_device_topic, topic);
  size_t payloadSize = strlen(msg);

  bool retain = false;
  int qos = 0;

  mqttClient.beginMessage(mqtt_topic, payloadSize, retain, qos, false);
  mqttClient.print(msg);
  mqttClient.endMessage();

  if (DEBUG) {
    Serial.println("");
    Serial.println("MQTT message published");
    Serial.print("  topic: ");
    Serial.print(mqtt_topic);
    Serial.println("");
    Serial.print("  message: ");
    Serial.println(msg);
    Serial.println("");
  }
}

void mqttPublishHA(char* topic, const char* msg) {
  char mqtt_topic[128] = "";
  strcpy(mqtt_topic, topic);
  size_t payloadSize = strlen(msg);

  bool retain = true;
  int qos = 1;

  mqttClient.beginMessage(mqtt_topic, payloadSize, retain, qos, false);
  mqttClient.print(msg);
  mqttClient.endMessage();
}

void mqttCallback(int length) {
  char payload[length];
  String topic = mqttClient.messageTopic();

  // get message
  for (int i = 0; i < length; i++) {
    payload[i] = (char)mqttClient.read();
    payload[i+1] = '\0';
  }

  if (DEBUG) {
    Serial.println("");
    Serial.print("Message arrived at ");
    Serial.print(topic);
    Serial.print(": ");  
    Serial.println(payload);
    Serial.println();
  }

  if (topic == mqtt_poll_topic) { // handle change of polling time
    char new_polling[length];
    strncpy(new_polling, (char*)payload, length);
    unsigned int new_polling_val = atoi(new_polling);
    if(new_polling_val != polling && new_polling_val < 86400) { // set max to 24h
      if (DEBUG) {
        Serial.print("Setting polling time to ");
        Serial.print(new_polling);
        Serial.println(" seconds");        
      }
      polling = new_polling_val;
      if(polling == 0) {
        Serial.println("Auto polling disabled. Polling on request");
      }
    }
    if(polling == 0) {
      getSensors();
    }
  } else if (topic == mqtt_control_topic) { // handle 'restart' command
    char restcmd[length];
    strncpy(restcmd, (char*)payload, length);
    if (!strcmp(restcmd, "restart")) {
      mqttPublishStatus(0);
      restartDevice();
    }
  }
}
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

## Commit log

2022-02-24 Misc files added
    [PWS_I2C_Sensors.kicad_pcb, PWS_I2C_Sensors.sch, PWS_MCU.kicad_pcb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]
2023-04-18 MQTT improvement and fixes
    [PWS_IoT.ino]
2023-04-18 Agregating wind sensors
2024-06-03 SparkFunMLX90614 replaced by Adafruit_MLX90614
    [PWS_IoT.ino]
